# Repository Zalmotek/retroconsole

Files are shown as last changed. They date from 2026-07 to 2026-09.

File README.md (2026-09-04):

# RetroConsole — Arduino UNO Q Retro Game Console

A retro gaming console built on the Arduino UNO Q running Debian Linux, using
RetroArch for emulation with custom Modulino-based controls and an 8″ DSI
touchscreen on the UNO Media Carrier. Boots straight into the game menu —
no keyboard, no desktop.

It optionally also plays the [ARC-AGI-3](#optional-arc-agi-3-puzzle-games)
abstract-reasoning games, on the same gamepad.

Full build write-up: see the project on Arduino Project Hub.

## Architecture

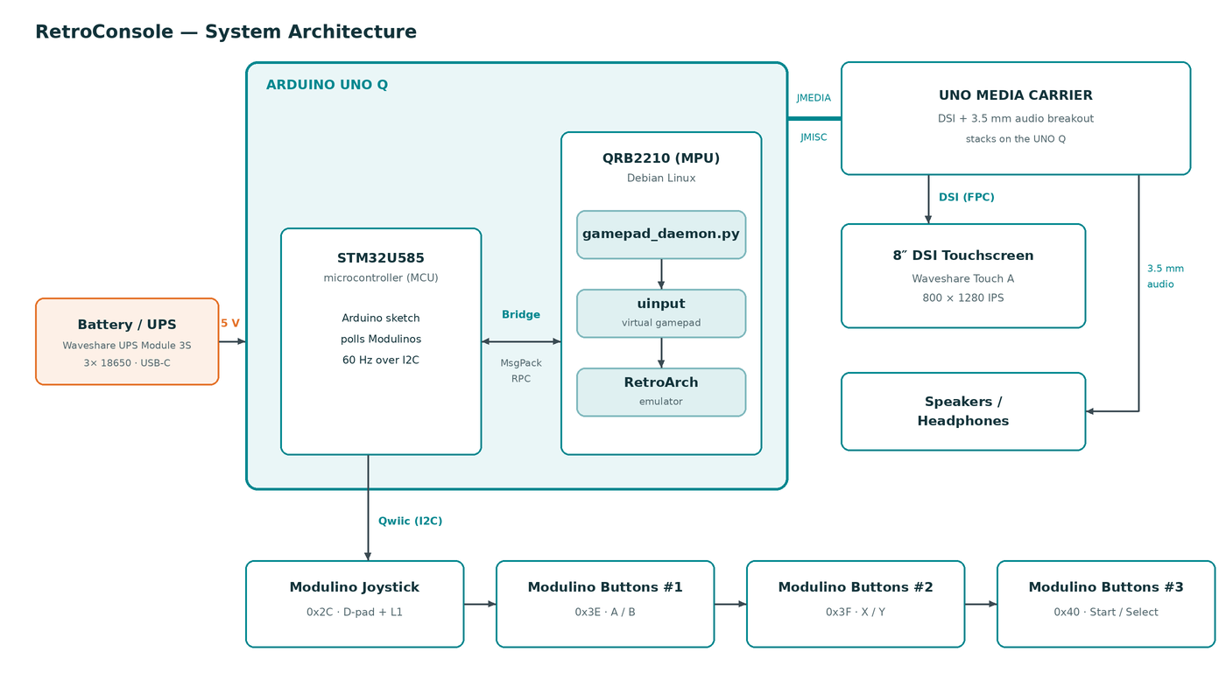
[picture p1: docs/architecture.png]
RetroConsole system architecture


(Diagram source: [`docs/architecture.py`](docs/architecture.py) — edit and re-run to regenerate.)

Each Buttons module contributes only its two **exterior** buttons — the three
buttons sit too close together for the middle one to be usable, so three
modules cover the six actions.

## Hardware

| Component | Purpose | Link |
|---|---|---|
| Arduino Uno Q | Main computing unit (Cortex-A53 + STM32) | [Docs](https://docs.arduino.cc/hardware/uno-q) |
| Uno Media Carrier | DSI display output + 3.5mm audio | [Docs](https://docs.arduino.cc/hardware/uno-media-carrier/) |
| Waveshare 8" DSI touch display (8-DSI-TOUCH-A) | 800x1280 IPS display | [Wiki](https://www.waveshare.com/wiki/8-DSI-TOUCH-A) |
| Waveshare UPS Module 3S + 3x 18650 cells | Battery power / UPS | [Wiki](https://www.waveshare.com/wiki/UPS_Module_3S) |
| Adafruit mono enclosed speaker (3W 4Ω) | Speaker for the enclosed build (earpiece-amp output) | [Adafruit](https://www.adafruit.com/product/4445) |
| USB-C 2-in-1 PD + data adapter | PD power in + USB peripherals on the single USB-C port | [eMAG](https://www.emag.ro/adaptor-usb-c-cu-incarcare-pd-transfer-rapid-12cm-gri-21-typc-2in1/pd/DX295PYBM/) |
| Modulino Buttons x3 | 6 action buttons (A/B/X/Y/Start/Select), exterior pair of each module | [Docs](https://docs.arduino.cc/hardware/modulino-buttons/) |
| Modulino Joystick | Directional control | [Docs](https://docs.arduino.cc/hardware/modulino-joystick/) |

## Wiring

```
[Uno Q] --JMEDIA/JMISC--> [Media Carrier] --15pin FPC--> [Waveshare 8" DSI]
                                |
                                | 3.5mm audio out --> [Speakers/Headphones]

[Uno Q Qwiic] --> [Joystick 0x58] --> [Buttons #1 0x7C] --> [Buttons #2 0x7D] --> [Buttons #3 0x80]
```

## Button Mapping

```
Joystick X/Y   → D-pad (Up/Down/Left/Right)   [both axes inverted in daemon
                                                to match the physical mount]
Joystick Press → L1 (also Hotkey + L1 closes content)
Buttons #1     → A, B          (exterior buttons; middle unused)
Buttons #2     → X, Y          (exterior buttons; middle unused)
Buttons #3     → Start, Select (exterior buttons; middle unused)
```

### Hotkey combos

`Select` is the hotkey modifier. Hold `Select` and press:

| Combo | Action |
|---|---|
| Select + Start | Toggle the in-game menu overlay |
| Select + L1 | Close the running game and return to the (landscape) menu |

Escape is **disabled** as a quit key so a stray USB keypress can't drop the
kiosk to XFCE. To actually quit RetroArch entirely: SSH in and `pkill retroarch`.

## App Lab project bundles

Pre-built zips importable directly into Arduino App Lab live in `dist/`:

- `dist/game-console.zip` — the gameplay sketch + Python skeleton
- `dist/modulino-i2c-changer.zip` — I2C address-change utility (one run per
  extra Buttons module with an explicit target address; see its README)
- `dist/bus-scanner.zip` — Qwiic bus scanner; prints ACKing addresses to the
  App Lab Monitor. Use it to verify the chain and to disarm the changer.
- `dist/recovery-changer.zip` — fixes address collisions (two modules on one
  address) one module at a time.
- `dist/button-checker.zip` — prints every button press/release with its
  gamepad role (A/B/X/Y/Start/Select, D-pad, L1) to the Monitor; standalone
  end-to-end input test before flashing the gameplay sketch.

Re-run `bash dist/build.sh` after editing any source file in `game-console/`
or `modulino-i2c-changer/` to refresh the zips.

## 3D-printed parts

Enclosure files live in [`3d/`](3d/) — STL for printing plus editable source
files.

## Provisioning a Unit

The console is built from three layers, each with its own deployment step. The
order matters — the Linux-side install (Step 4) requires the App Lab project
to have been deployed at least once (Step 3) so the Arduino Router socket and
the `python-apps-base` Docker container exist on the device.

### 1. First boot in App Lab

Install the **latest Arduino App Lab** on your workstation, connect the UNO Q
over USB-C, and complete the first-time setup: set a device name and password,
join Wi-Fi, **enable SSH** in App Lab settings. If App Lab offers an OS
update, take it — the current image ships the Touch A panel drivers and the
`arduino-linux-config` carrier tool, so no manual image flashing is needed.
The steps below assume the device name `retroconsole` — substitute your own.

### 2. Hardware preparation

a. Connect the Uno Q + Media Carrier + Waveshare 8-DSI-TOUCH-A panel +
   speakers. Power via USB-C.
b. **Renumber Buttons #2 and #3** using `dist/modulino-i2c-changer.zip` in
   App Lab (all three Buttons modules ship at the same `0x3E`). Two runs,
   one module attached at a time, editing `NEW_ADDR` between them:
   `0x3F` for #2, `0x40` for #3. Verify each by unplug/replug (blinking
   resumes = persisted), then flash `dist/bus-scanner.zip` to disarm the
   changer and confirm the full chain shows `0x2C, 0x3E, 0x3F, 0x40`.

   Full routine, Monitor/LED codes, and collision recovery:
   [`modulino-i2c-changer/README.md`](modulino-i2c-changer/README.md).
c. Daisy-chain Qwiic in this order:
   `Uno Q → Joystick → Buttons #1 → Buttons #2 → Buttons #3`.

### 3. MCU sketch + first App Lab deploy (workstation, one time)

Install Arduino App Lab on your workstation. Import `dist/game-console.zip`
into App Lab (`File → Import` accepts only zips), then press **Run**. App
Lab will:

- Compile and flash `game-console/sketch/sketch.ino` to the STM32U585 MCU.
  After this step the sketch lives in the MCU's flash and runs on every boot,
  no further App Lab deploys are needed.
- Provision the `python-apps-base` Docker container on the Linux side. We
  don't actually run the App Lab Python app — but the container image needs
  to be on disk so `setup.sh` can copy `arduino.app_utils` out of it.

After this one-time deploy you can disconnect the workstation. The MCU sketch
will run from flash on every boot.

> **Important:** in App Lab's project settings tick **"Run at startup"** on the
> game-console app — otherwise the MCU sketch won't fire on every boot and
> the Linux-side gamepad daemon will see no Bridge traffic.

### 4. Linux-side install (run on the Q)

```bash
ssh arduino@retroconsole.local
git clone https://github.com/Zalmotek/retroconsole.git
cd retroconsole
sudo bash setup.sh
sudo reboot
```

`setup.sh` is idempotent — running it again on a configured unit is harmless.
After the reboot the Q autologs `arduino`, RetroArch starts fullscreen, the
gamepad daemon is already running as a service, and the console is playable.

### 5. DSI panel (enabled automatically by setup.sh)

`setup.sh` enables the Media Carrier + Touch A panel natively via
`arduino-linux-config` (the App Lab carrier tool) — no manual DTB hacking.
It is a no-op when the carrier is already configured, and can be skipped
with `KIOSK_DISPLAY=none sudo bash setup.sh` (HDMI/bench setups). The change
takes effect on the same reboot as the rest of the setup. Manual equivalent:

```bash
sudo arduino-linux-config carrier enable media-carrier display=8-dsi-touch-a
sudo reboot
```

Use `5-dsi-touch-a` / `10-dsi-touch-a` for the other panel sizes
(`arduino-linux-config carrier list` shows the options; `carrier show`
prints the current/next-boot state). On reboot the panel's DRM connector
reports `card0-DSI-1: connected` at its **native `800x1280`** (portrait);
Xorg's rotate-left then presents it as 1280x800 landscape. It's driven by
`panel_jadard_jd9365da_h3` (JD9365, compatible `jadard,jd9365da-h3` /
`waveshare,8.0-dsi-touch-a`), and `arduino-linux-config` composes the
carrier+panel DTB for you. Verify the panel actually came up with:

```bash
sudo arduino-linux-config carrier show   # display -> current: 8-dsi-touch-a
cat /sys/class/drm/card0-DSI-1/status    # connected
cat /sys/class/drm/card0-DSI-1/modes     # 800x1280
```

> Note: enabling the carrier drops the `qrb2210-arduino-imola-video_sound-usbc.dtbo`
> overlay as incompatible — this is expected and is why HDMI-over-USB-C stops
> working (below).

> A fresh image ships with the carrier **disabled** and `display: none`, so
> the panel stays dark until this step runs — RetroArch then starts on a
> 320x200 dummy framebuffer with nothing visible. `carrier show` confirms.

The carrier reroutes the SoC's DSI lanes away from the on-board ANX7625 HDMI
bridge, so **HDMI over USB-C does not work while the carrier is enabled**. To
fall back to HDMI, `arduino-linux-config carrier disable media-carrier` and
physically remove the carrier.

### 6. Add ROMs

```bash
scp "Tobu Tobu Girl.gb" arduino@retroconsole.local:~/roms/gb/
```

Drop ROMs into `~/roms/{gb,gbc,gba,nes,snes,genesis}/` on the Q. RetroArch's
`Load Content` browser starts at `~/roms`. Good open-source homebrew to start
with: [Tobu Tobu Girl](https://tangramgames.dk/tobutobugirl/) (Game Boy) and
[Miniplanets](https://sik.itch.io/miniplanets) (Sega Genesis).

### Verification

If anything misbehaves, on the Q:

```bash
sudo systemctl status modulino-gamepad   # daemon up?
jstest /dev/input/js0                     # raw gamepad — press buttons
evtest /dev/input/event*                  # find 'Modulino Gamepad'
```

## Detailed Setup Guides

1. [OS Setup](setup/01-os-setup.md) — First boot, network, I2C verification
2. [Display Setup](setup/02-display-setup.md) — DSI connection via Media Carrier
3. [Audio Setup](setup/03-audio-setup.md) — Media Carrier line-out
4. [RetroArch Setup](setup/04-retroarch-setup.md) — Installation, config, auto-start

## Supported Systems

| System | Core | Performance |
|---|---|---|
| Game Boy / GBC | gambatte | Full speed |
| Game Boy Advance | mGBA | Full speed |
| NES | Nestopia | Full speed |
| SNES | snes9x | Full speed |
| Sega Genesis | genesis-plus-gx | Full speed |

## Optional: ARC-AGI-3 puzzle games

The console also runs the **ARC-AGI-3** benchmark — the interactive puzzle
games the ARC Prize Foundation uses to measure abstract reasoning. The games
give you no instructions at all: you work out the rules of each world by
acting in it and reading what changes.

```bash
sudo bash install_arc_agi_3_player.sh
```

The installer clones the upstream [Pygame player][arc-upstream], patches it
for a console with no keyboard, downloads the 25 games for offline play, and
adds dock launchers for both apps. It parks the RetroArch autostart, so the
two never fight for the display — you then tap either icon in the dock.

The gamepad drives everything: D-pad moves, A interacts, B undoes, Y resets,
Start opens the menu. The touchscreen covers the grid-click action.

See [arc-agi-3/README.md](arc-agi-3/README.md) for the options, the full
control map and how to restore the RetroArch kiosk.

[arc-upstream]: https://github.com/aashen1/arc-agi-3-local-play

## Project Structure

```
├── setup.sh                            # Idempotent provisioner (re-runnable)
├── game-console/                       # App Lab project — MCU sketch + Python skeleton
├── modulino-i2c-changer/               # App Lab project — 0x3E→0x3F/0x40 renumbering
├── bus-scanner/                        # App Lab project — Qwiic I2C bus scanner
├── recovery-changer/                   # App Lab project — address-collision recovery
├── button-checker/                     # App Lab project — serial button/mapping test
├── dist/                               # Pre-built .zip bundles for App Lab Import
├── modulino-gamepad/
│   ├── gamepad_daemon.py               # Bridge → uinput translator
│   └── modulino-gamepad.service        # systemd unit
├── retroarch/
│   └── modulino-gamepad.cfg            # udev autoconfig (button → RA mapping)
├── kiosk/
│   ├── 10-monitor-dsi-rotate.conf      # Xorg "Rotate left" default
│   ├── 99-touchscreen-rotate-left.rules# libinput touch calibration matrix
│   ├── ra-rotate-watcher.py            # Toggles xrandr on RA game start/exit
│   ├── ra-rotate-watcher.service       # systemd unit for the above
│   ├── retroarch-kiosk.desktop         # Xfce autostart for RetroArch
│   ├── retroarch-overrides.cfg         # RA cfg block appended by setup.sh
│   ├── kiosk-session-watchdog.sh       # Restarts RetroArch if it dies
│   ├── audio-tune.sh                   # Codec tuning re-applied on WirePlumber start
│   ├── usb-host-mode.service           # Forces USB-C to host mode at boot
│   └── 99-kiosk.conf                   # sysctl: disable Magic SysRq
├── 3d/                                 # Enclosure — STL + editable sources
├── setup/                              # Step-by-step guides (hardware focus)
├── install_arc_agi_3_player.sh         # Optional: ARC-AGI-3 puzzle games
└── arc-agi-3/                          # Gamepad bridge, patcher, icon, dock entries
```

## Kiosk Architecture

### Display rotation strategy

The Touch A panel is native portrait 800×1280. The user holds it landscape.
Two facts collide:

1. Xorg's software rotation (`Rotate "left"`) introduces a per-frame
   copy+rotate pass that **races the panel scanout**, producing a fixed-position
   tearline (~70% of the screen width) during horizontal scrolling.
2. RetroArch can rotate its own content inside its swapchain
   (`video_rotation = "1"`), which is tear-free, but only the *game* content
   — the RA menu inherits the screen orientation from the OS.

We get the best of both with a dynamic toggler:

| State | Xorg rotation | RA video_rotation | Result |
|---|---|---|---|
| Menu (no game) | `left` | `1` | Menu reads landscape via X; no scroll → no tear |
| Game running | `normal` | `1` | RA rotates content in swapchain; tear-free |

`kiosk/ra-rotate-watcher.py` polls RetroArch's network command interface
(`GET_STATUS` on UDP 55355) and flips `xrandr --output DSI-1 --rotate` when
content loads / unloads. Installed by `setup.sh` as `ra-rotate-watcher.service`.

### Anti-tearing knobs (`kiosk/retroarch-overrides.cfg`)

- `video_driver = "vulkan"` — Vulkan via Turnip Adreno; presents through
  DRM atomic, tear-free under the msm driver
- `video_vsync = "true"` + `video_hard_sync = "true"` + `video_max_swapchain_images = "3"`
- `video_frame_delay_auto = "true"` — RA times each frame to land just before VBLANK
- xfwm4 compositor disabled (`use_compositing = false`) so RA's vsync isn't
  decoupled by a second compositor

### Audio output modes

`setup.sh` installs `audio-tune.service`, which re-applies codec tuning every
time WirePlumber starts. Two output modes, selected by `/etc/kiosk-audio-output`
(an existing mode file is preserved on re-runs):

- `earpiece` (default) — mono Class-AB earpiece amp driving a bare speaker,
  with a stereo→mono downmix sink (`kiosk/51-earpiece-mono-sink.conf`); for
  the enclosed build
- `headphones` — stereo out on the Media Carrier's MIC-IN/Headphones combo
  jack; for bench builds. Select at provision time:
  `KIOSK_AUDIO_OUTPUT=headphones sudo bash setup.sh`

### USB host mode

`kiosk/usb-host-mode.service` flips the USB-C port from "device" (App Lab
peripheral) to "host" on boot, so external keyboards + USB hubs work. To
re-enable App Lab over USB temporarily, two steps are needed — App Lab talks
ADB, and `adbd` only creates its USB gadget at service start (which happened
while the port was still in host mode), so it must be restarted *after* the
role flip:
```bash
echo device | sudo tee /sys/devices/platform/soc@0/4ef8800.usb/4e00000.usb/usb_role/4e00000.usb-role-switch/role
sudo systemctl restart adbd
```
Verify with `ls /sys/kernel/config/usb_gadget/` — a `g1` entry must exist,
bound to the UDC (`cat /sys/kernel/config/usb_gadget/g1/UDC` → `4e00000.usb`).
If App Lab still shows no device, replug the USB-C cable at the PC end.
Reverts to host mode on the next reboot.

### Touch calibration

The Goodix driver reports `abs_max=4095` but only uses ~0..800 (X) and
~0..1280 (Y) — the panel's pixel coords. `kiosk/99-touchscreen-rotate-left.rules`
applies a scaling matrix (`5.120 0 0 0 3.199 0`) via libinput to map raw
touch onto the X portrait coordinate space; Xorg's RandR rotation handles
the rest when the screen flips.

## Notes

- The Qwiic I2C bus is controlled by the MCU, not Linux. Data flows: Modulinos → MCU (I2C) → Bridge → Linux (Python) → uinput → RetroArch.
- All three Modulino Buttons modules ship at default address `0x3E` (=`0x7C` 8-bit form). Buttons #2 and #3 must be renumbered to `0x3F` and `0x40` using `dist/modulino-i2c-changer.zip` before use — see `modulino-i2c-changer/README.md` for the routine.
- Only the exterior buttons (indices 0 and 2) of each Buttons module are mapped; the middle button is physically too close to its neighbours and is left unused (its LED stays off).
- Carrier presence reroutes the SoC's DSI lanes from the on-board ANX7625 HDMI bridge to the carrier's DSI0 connector — so **HDMI does not work while the carrier is enabled**.
- The MCU sketch must be set to **"Run at startup"** in App Lab; otherwise Bridge stays silent on boot and the gamepad daemon receives no input.
- Bridge.notify() is used for fire-and-forget data transfer (~8ms overhead per call).

## License

MIT — see [LICENSE](LICENSE). Built by [Zalmotek](https://zalmotek.com).

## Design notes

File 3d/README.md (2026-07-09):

# 3D-printed enclosure

- `*.stl` — print-ready meshes
- editable source files (STEP / Fusion 360)

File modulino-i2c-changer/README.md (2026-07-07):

# Modulino I2C Address Changer

Arduino App Lab utility that renumbers a Modulino's I2C address so multiple
modules of the same type can share a Qwiic bus.

The retro-console uses **three Modulino Buttons** (only the exterior pair of
each is mapped — the middle button is too cramped to use). All three ship at
the same factory address, so two of them must be renumbered before the
gamepad sketch can tell them apart:

```
Buttons #1  0x3E  (factory — untouched)
Buttons #2  0x3E → 0x3F
Buttons #3  0x3E → 0x40
```

The changer is **deterministic**: you set the target address explicitly in
the sketch for each run. There is no auto-assignment on purpose — a
half-seated Qwiic connector makes an occupied address look free, which is
how you end up with two modules on one address (see Recovery below).

## From-scratch routine (new unit, 3 fresh Buttons modules)

**Rule 1: exactly one Buttons module on the chain per run.** An I2C write
reaches every device at that address, so two factory modules attached at
once would both be renumbered.
**Rule 2: the changer re-runs on every MCU reset while it's in flash.**
Its guards make that mostly harmless, but always finish with step 5.

The Joystick (0x2C) can stay attached throughout.

1. **Run 1 — make Buttons #2:** attach one Buttons module (alone). Open this
   project in App Lab and press **Run** with the sketch as shipped
   (`NEW_ADDR = 0x3F`). Watch the Monitor: `SUCCESS` + a bus scan. The
   module's three LEDs blink in unison.
2. **Persistence check:** unplug and replug that module. The blinking
   resumes → the address survived the power-cycle. Label the module **#2**
   and detach it.
3. **Run 2 — make Buttons #3:** edit one line in the sketch —
   `NEW_ADDR = 0x40` — attach the second module (alone), press **Run**.
   Same checks. Label it **#3**, detach it.
4. The third module is **Buttons #1**: it stays at the factory `0x3E` —
   no run. Label it anyway.
5. **Disarm:** run the `bus-scanner` app (import `dist/bus-scanner.zip`).
   This removes the changer from MCU flash so later resets can't renumber
   anything, and doubles as the verifier for the next step.
6. **Verify the full chain:** connect
   `Uno Q → Joystick → #1 → #2 → #3` and read the Monitor. It must list
   `0x2C, 0x3E, 0x3F, 0x40`. A missing address = bad connector or cable on
   that segment — reseat until all four show.
7. Flash the gameplay sketch (`game-console`) and test all six buttons.

## Monitor + LED feedback

The Monitor prints the bus before/after and one of:

| Message | Meaning |
|---|---|
| `SUCCESS` | renumbered and verified at the new address |
| `Already at target — nothing to do.` | harmless re-run after a success |
| `REFUSING: target address already in use…` | another module owns NEW_ADDR — detach it first; nothing was changed |
| `FAILED: no module at CURRENT_ADDR…` | nothing answered — almost always a half-seated Qwiic connector |

LEDs on the module: **all three blinking** = success / already done;
**only LED 0** = failed or refused (read the Monitor); **no LEDs** = no
module answered at all.

## Recovery: two (or more) modules on the same address

If addresses ever collide (the classic symptom: a button reads stuck-on,
LEDs won't clear, or the scanner shows fewer Buttons than are attached),
use the `recovery-changer` app (`dist/recovery-changer.zip`): attach **one
module alone**, set its
`NEW_ADDR` to where that module belongs (`0x3E` / `0x40`; the one that
should be #2 needs no run if it's already at `0x3F`), Run, persistence-check,
repeat per module. Finish with the disarm + full-chain verify (steps 5–6).

## Notes

- The address is stored in the module's own flash (non-volatile) — this is
  a once-per-unit operation. Label the modules so units don't get mixed.
- Distance, Thermo, and Movement modules have hardware-fixed addresses and
  cannot be changed.
- If App Lab can't see the board (kiosk image flips USB-C to host mode on
  boot): see "USB host mode" in the main README — role flip to `device`
  **plus** `systemctl restart adbd`.

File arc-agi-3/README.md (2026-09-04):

# ARC-AGI-3 on the Retro Game Console

Turn the console into a machine for the **ARC-AGI-3** benchmark — the
interactive puzzle games the ARC Prize Foundation uses to measure abstract
reasoning. You play them with the Modulino gamepad and the touchscreen.

The games give you no instructions. No tutorial, no goal text, no legend for
the colours. You work out the rules of each world by acting in it and reading
what changes. That is the whole point of the benchmark: it measures how fast a
player builds a theory from nothing. Today humans beat every frontier AI model
on it by a wide margin, and this console lets you feel exactly why.

## What you get

- **25 games**, each with several levels, downloaded once and then played
  fully offline. No account and no API key.
- **Gamepad control.** D-pad moves, A interacts, B undoes, Y resets, Start
  opens the menu. The D-pad auto-repeats when held, for menu scrolling.
- **Touch control** for the grid click action, which some games need, and for
  the menus.
- **Player profiles.** Each player keeps their own progress, level unlocks and
  statistics, so several people can share one console.
- **Replays**, saved in a lightweight JSONL log and in the official ARC-AGI-3
  recording format.
- **RetroArch stays.** Both apps sit in the dock. Tap one to play puzzles,
  tap the other for retro games.

The player is [aashen1/arc-agi-3-local-play][upstream], a Pygame front end for
the official `arc-agi` toolkit. This directory adds what the console needs:
gamepad input, fullscreen, the icon and the dock entries.

## Install

On the console, with a network connection:

```bash
git clone https://github.com/Zalmotek/retroconsole.git ~/retroconsole
cd ~/retroconsole
sudo bash install_arc_agi_3_player.sh
```

It takes about ten minutes, most of it building the Python environment. When
it finishes, tap the **ARC-AGI-3** icon in the dock.

Run `setup.sh` first if the console is new — this script assumes the DSI
panel, the gamepad daemon and the audio are already provisioned.

### Options

| Variable | Effect |
|---|---|
| `ARC_KEEP_KIOSK=1` | Keep RetroArch starting at boot. |
| `ARC_SKIP_DOWNLOAD=1` | Skip the game download, for a console with no network. Press **Sync** in the app later. |
| `ARC_APP_DIR=<path>` | Install somewhere other than `~/arc-play`. |
| `ARC_UPSTREAM_REF=<ref>` | Pin a different upstream commit or tag. |

### What it changes

- Installs the player to `~/arc-play`, in its own Python virtual environment.
  Not pixi: the upstream `pixi.toml` has no `linux-aarch64` platform, and every
  dependency ships an aarch64 wheel, so a plain venv needs no compiler.
- Adds two launchers to the XFCE dock, makes the dock 100 px tall with 80 px
  icons, and turns off autohide. On this 8-inch panel an 80 px icon is about
  10.8 mm, above the 9 mm a fingertip needs.
- Parks the RetroArch autostart as
  `~/.config/autostart/retroarch-kiosk.desktop.disabled`. Both apps want the
  whole display, so only one may start at boot. Restore the old kiosk with:

  ```bash
  mv ~/.config/autostart/retroarch-kiosk.desktop{.disabled,}
  ```

## Controls

| Button | In a menu | In a game |
|---|---|---|
| D-pad | Navigate | Move up, down, left, right |
| A | Confirm | Interact |
| B | Back | Undo |
| X | — | Undo |
| Y | — | Reset the level |
| Start | Confirm | Back to the menu |
| Touch | Tap a button | Tap the grid, for the click action |

On the resume prompt: **A** continues, **X** starts a new game, **Y** opens
level select, **B** goes back.

## Files

| File | Purpose |
|---|---|
| `gamepad.py` | Turns gamepad buttons into key events, per screen. Copied into `human_player/`. |
| `patch-upstream.py` | Adds the gamepad and fullscreen hooks to the upstream checkout. Idempotent, and it stops with a clear message if upstream has moved. |
| `arc-play.sh` | The launcher. Sets an absolute `ENVIRONMENTS_DIR`, forces fullscreen, stops the screen blanking. |
| `panel-launchers/` | The two dock entries. |
| `icons/` | The ARC Prize mark, 16 to 256 px. |

[upstream]: https://github.com/aashen1/arc-agi-3-local-play

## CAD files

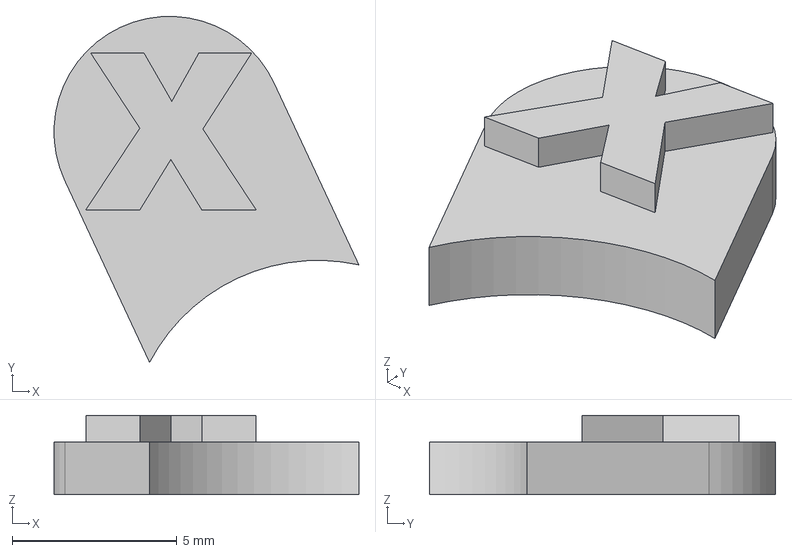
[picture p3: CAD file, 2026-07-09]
3d/x_label.step
9.24 x 10.5 x 2.40 mm

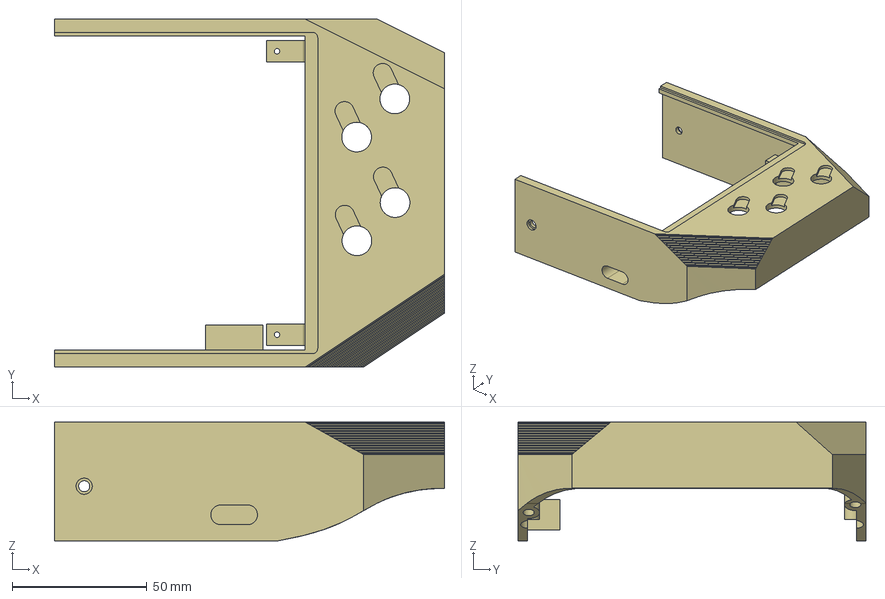
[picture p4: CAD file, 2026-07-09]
3d/console_front_right.step
144.5 x 129.0 x 44.0 mm

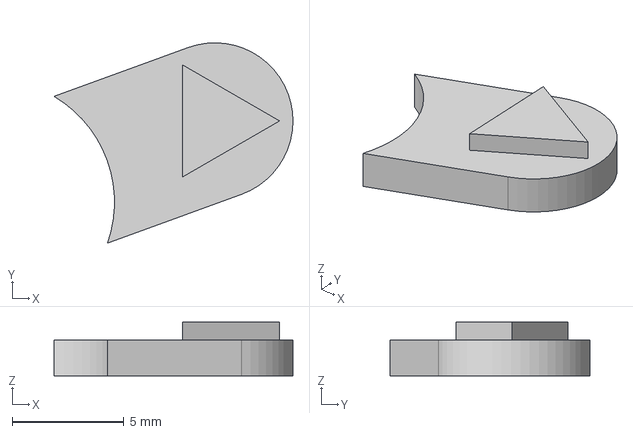
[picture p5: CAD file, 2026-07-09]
3d/menu_label.step
10.7 x 8.98 x 2.40 mm

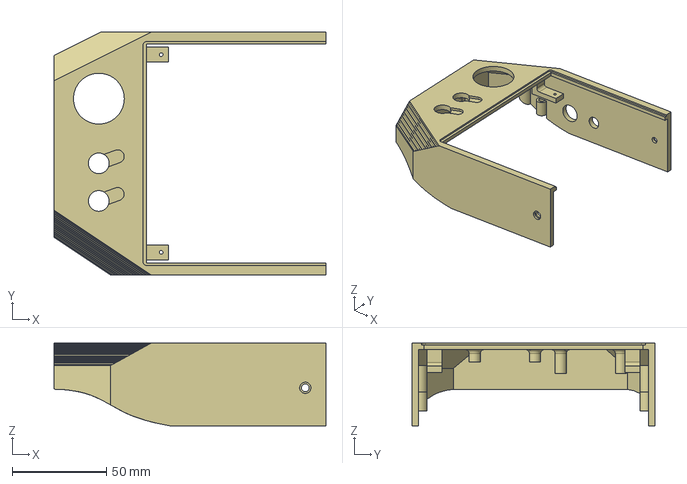
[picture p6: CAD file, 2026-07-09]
3d/console_front_left.step
144.5 x 129.0 x 44.0 mm

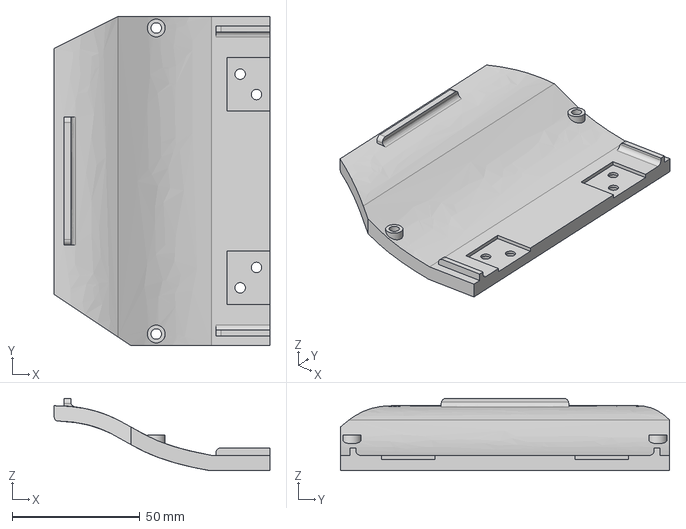
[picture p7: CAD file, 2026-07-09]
3d/console_back_left.step
84.5 x 129.0 x 28.4 mm

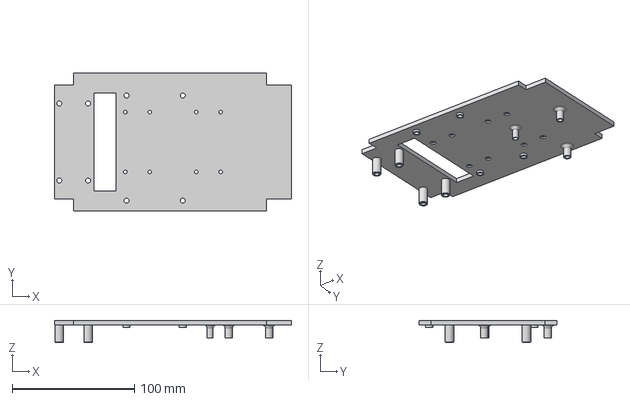
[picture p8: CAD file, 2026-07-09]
3d/modules_mounting_board.step
194.0 x 113.0 x 18.2 mm

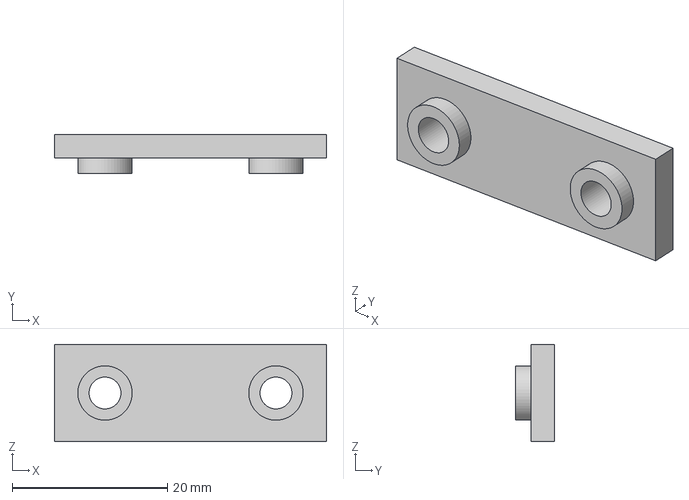
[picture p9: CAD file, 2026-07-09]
3d/fastner.step
35.0 x 5.00 x 12.5 mm

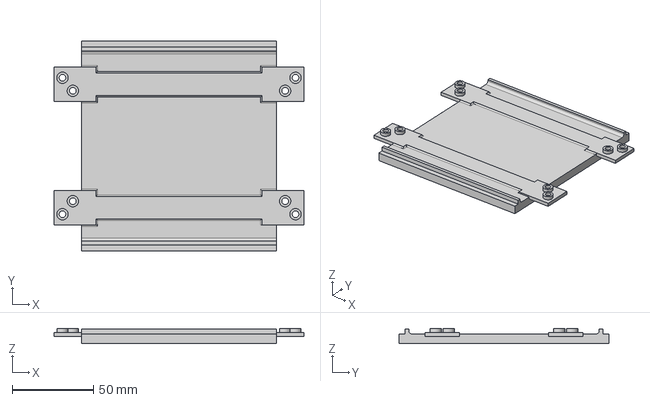
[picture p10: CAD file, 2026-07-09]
3d/console_back_mid.step
153.6 x 129.0 x 9.50 mm

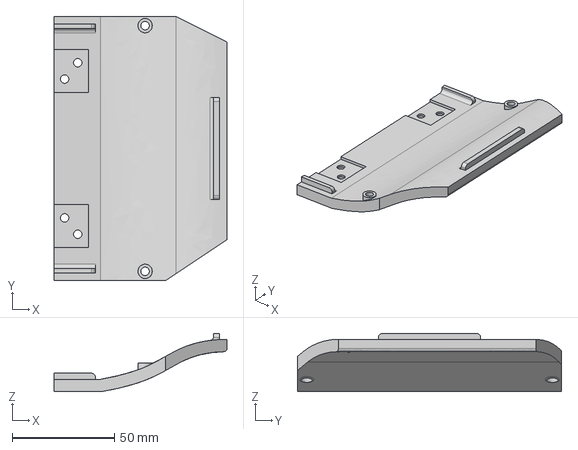
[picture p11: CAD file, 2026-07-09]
3d/console_back_right.step
84.5 x 129.0 x 28.4 mm

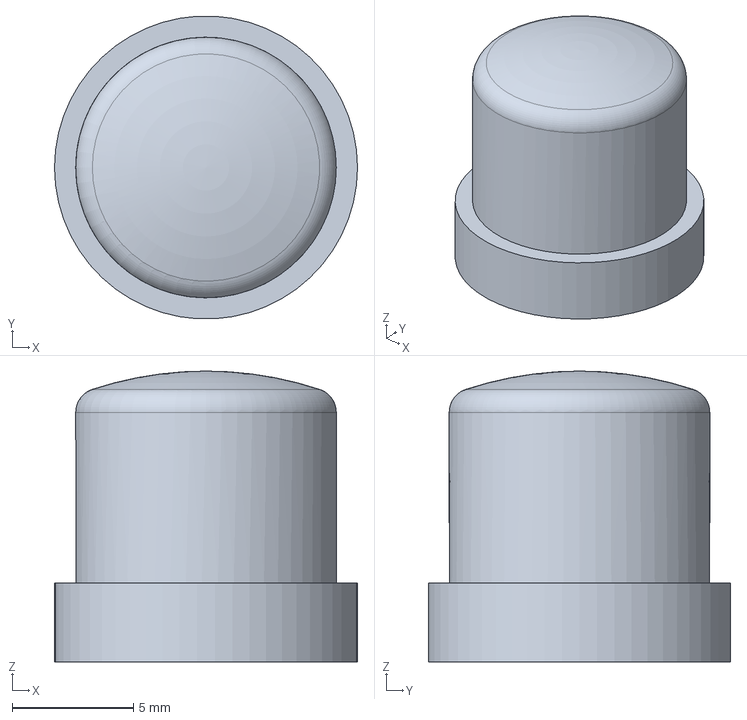
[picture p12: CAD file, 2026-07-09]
3d/button.step
12.5 x 12.5 x 12.0 mm

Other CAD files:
3d/a_label.step
3d/y_label.step
3d/select_label.step
3d/b_label.step
3d/a_label.stl
3d/b_label.stl
3d/button.stl
3d/console_back_left.stl
3d/console_back_mid.stl
3d/console_back_right.stl
3d/console_front_left.stl
3d/console_front_right.stl
3d/fastner.stl
3d/menu_label.stl
3d/modules_mounting_board.stl
3d/x_label.stl
3d/y_label.stl

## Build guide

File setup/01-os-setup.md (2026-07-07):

# OS Setup — Arduino Uno Q

## Prerequisites

- Arduino Uno Q with Debian already flashed
- USB-C cable
- Arduino App Lab on your PC (https://www.arduino.cc/en/software)

## First-Time App Lab Connection

1. Connect the Uno Q to your PC via USB-C
2. Open Arduino App Lab
3. The board will auto-check for firmware/OS updates — install if prompted
4. Set device name, password, and Wi-Fi credentials

## Network Access

After initial setup, you can connect via SSH over Wi-Fi:

```bash
# From your PC
ssh arduino@<device-name>.local
# Default password: set during first-time setup
```

Or connect via USB-C (gadget ethernet):

```bash
ssh arduino@192.168.7.1
```

## Verify I2C (Qwiic bus)

The Qwiic I2C bus is managed by the MCU, not directly accessible from Linux. To verify Modulino devices are connected:

1. Open Arduino App Lab
2. Upload the `File > Examples > Arduino_Modulino > Modulino_Scanner` sketch
3. Check Serial Monitor — it should list detected devices at 0x58, 0x7C, 0x7D

## System Packages

```bash
sudo apt update && sudo apt upgrade -y
sudo apt install -y git python3-pip evtest i2c-tools alsa-utils
```

## Clone This Repo

```bash
git clone <repo-url>
cd retroconsole
```

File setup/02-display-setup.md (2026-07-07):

# Display Setup — Waveshare 8" DSI LCD via Media Carrier

## Enable the panel (native — current method)

The carrier + panel are enabled in software via `arduino-linux-config` (the App
Lab carrier tool) — **no DTB hacking**. A fresh image ships the carrier
**disabled** with `display: none`, so the panel is dark until you run:

```bash
sudo arduino-linux-config carrier enable media-carrier display=8-dsi-touch-a
sudo reboot
```

- `arduino-linux-config carrier list` — show available devices/options
  (`display`: `none, 5-dsi-touch-a, 8-dsi-touch-a, 10-dsi-touch-a`).
- `arduino-linux-config carrier show` — current vs next-boot state.

After reboot the panel is `card0-DSI-1: connected` @ 1280x800, driven by
`panel_jadard_jd9365da_h3` (JD9365). The carrier reroutes the DSI lanes off the
on-board ANX7625, so HDMI-over-USB-C is unavailable while the carrier is enabled
(`carrier disable media-carrier` + remove carrier to use HDMI).

## Hardware Connection

1. Power off the Uno Q
2. Attach the **Uno Media Carrier** via the JMEDIA + JMISC board-to-board connectors
3. Lift the locking tab on the Media Carrier's 22-pin DSI connector
4. Insert the Waveshare display's FPC ribbon cable (contacts facing down)
5. Press the locking tab down to secure

## Boot and Check

Power on. The display may work immediately if the BSP recognizes it.

```bash
# Check DRM/KMS devices
ls /sys/class/drm/

# Look for a connected display
cat /sys/class/drm/card0-DSI-1/status 2>/dev/null

# Check kernel messages for DSI
dmesg | grep -i dsi
dmesg | grep -i panel
```

## If the Display Works

Great — skip to audio setup. RetroArch will use KMS/DRM directly.

Verify with:
```bash
# Should show noise on the display
cat /dev/urandom > /dev/fb0
```

## If the Display Doesn't Work

The Media Carrier officially supports the **Waveshare 8-DSI-TOUCH-A**. The 8" DSI LCD (C) uses the same MIPI-DSI connector but may have a different panel init sequence.

Options:
1. **Check for firmware updates** in Arduino App Lab — newer BSPs may add panel support
2. **Check available DT overlays**: `ls /boot/overlays/ 2>/dev/null || ls /boot/dtbs/`
3. **Use HDMI via USB-C as fallback** — the Uno Q supports DisplayPort Alt-Mode over USB-C, which works with HDMI adapters out of the box

### USB-C HDMI Fallback

If DSI doesn't work, connect a USB-C to HDMI adapter:
```bash
# Display should appear automatically
# Optimal resolution: 1280x720 or 1920x1080
```

## Touch (if DSI works)

The Waveshare capacitive touch controller (Goodix) has a mainline Linux driver:

```bash
# Check if touch device is detected
cat /proc/bus/input/devices | grep -A5 -i touch

# Test
evtest  # select the touch device
```

Touch isn't needed for RetroArch gaming (we use Modulino controls), but it's useful for menu navigation.

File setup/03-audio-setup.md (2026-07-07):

# Audio Setup — Uno Media Carrier

## Hardware

The Uno Media Carrier has a 3.5mm line-out jack. Connect powered speakers or headphones.

## Software Configuration

### Verify Audio Device

```bash
# List audio devices
aplay -l

# You should see an audio device from the Media Carrier
# Look for something like "qrb2210" or "sm8250" audio
```

### Test Audio Output

```bash
# Install audio tools
sudo apt install -y alsa-utils

# Generate and play a test tone
speaker-test -t sine -f 440 -c 2 -l 1

# Or play a WAV file
aplay /usr/share/sounds/alsa/Front_Center.wav
```

### Set Default Output

If multiple audio devices exist, set the Media Carrier as default:

```bash
# Find card number from aplay -l output
# Edit ALSA config
cat > ~/.asoundrc << 'EOF'
defaults.pcm.card 0
defaults.pcm.device 0
defaults.ctl.card 0
EOF
```

### Volume Control

```bash
# Set volume (0-100)
amixer set Master 80%

# Or use interactive mixer
alsamixer
```

## RetroArch Audio Config

RetroArch routes through PipeWire's PulseAudio shim (`pipewire-pulse` is active;
WirePlumber auto-configures the Imola codec headphone path on card 0, so the raw
`amixer` pipeline from the Media Carrier manual is NOT needed). These are applied
by `setup.sh` via `kiosk/retroarch-overrides.cfg`:

```
audio_driver = "pulse"
audio_device = ""
audio_enable = "true"
audio_mute_enable = "false"   # default profile ships this as "true" → silent games
audio_sync = "true"
audio_latency = "64"
```

## Codec tuning (headphone amp quality)

The Imola codec headphone amp comes up in a low-power, distorting default. Tuned
values (chosen by listening test) are applied by `audio-tune.service`, a user
service bound to `wireplumber.service` (so it re-runs whenever WirePlumber
restarts and resets the codec):

```
amixer -c0 sset 'RX_HPH PWR Mode' ULP      # best with the current amp board
amixer -c0 sset 'RX_HPH HD2 Mode' on       # 2nd-harmonic distortion correction
wpctl set-volume @DEFAULT_AUDIO_SINK@ 0.90 # source level; final loudness on amp
# balance: WirePlumber drives only RX_RX1 (right) from the sink slider, so mirror
# left = right AFTER setting the sink, or the channels are uneven:
RIGHT=$(amixer -c0 cget iface=MIXER,name='RX_RX1 Digital Volume' | grep -oE 'values=[0-9]+' | tail -1 | cut -d= -f2)
amixer -c0 cset iface=MIXER,name='RX_RX0 Digital Volume' "$RIGHT"
```

> **Channel balance gotcha:** `RX_RX1 Digital Volume` (right) *is* the sink
> volume — WirePlumber maps the slider onto it and leaves `RX_RX0` (left)
> alone, so the two channels drift apart. There's no independent "set codec to
> N and sink to M"; the right codec value is whatever the slider dictates. The
> only fix is to mirror left = right after the sink is set (audio-tune.sh does
> this automatically each boot).

- `RX_HPH PWR Mode`: the best mode is **amp-dependent**. `LOHIFI` won on the
  first amp; `ULP` won on the current amp board. Re-run the listening test
  (A: LOHIFI+HD2on, B: LOHIFI+HD2off, C: ULP+HD2on, D: ULP+HD2off) if the amp changes.
- `RX_HPH HD2 Mode`: `on` consistently helped; `off` was audibly worse.
- **Do NOT touch `RX INT0/1 DEM MUX`** — switching Class-H (`CLSH_DSM_OUT`) to
  `NORMAL_DSM_OUT` silences the headphone output entirely, and toggling it live
  wedges the codec until `systemctl --user restart wireplumber`.
- The `HPHL`/`HPHR` analog gain spans only ~1.4 dB — useless as a volume control.
- For an external amp: keep the digital sink moderate (~50%) and set final
  loudness on the amp; the dedicated **Line Out (`hw:0,1`) is mono/differential**,
  not a stereo line out.

## Troubleshooting

- **No sound in games but system beep works**: RetroArch is muted —
  `audio_mute_enable = "true"`. Set it to `"false"` (setup.sh pins this), or
  live-toggle on the running kiosk: `echo -n MUTE | nc -u -w1 127.0.0.1 55355`.
- **No sound**: Check `amixer` isn't muted, verify correct card in `aplay -l`,
  and that the default sink is at volume: `wpctl get-volume @DEFAULT_AUDIO_SINK@`
- **Crackling**: Increase `audio_latency` in RetroArch (try 128)
- **No audio device**: Media Carrier may need kernel module; check `dmesg | grep audio`

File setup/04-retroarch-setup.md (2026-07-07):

# RetroArch Setup

## Installation

```bash
# Install RetroArch and common cores
sudo apt install -y retroarch \
  libretro-gambatte \
  libretro-snes9x \
  libretro-mgba \
  libretro-genesis-plus-gx \
  libretro-nestopia

# If packages aren't available, build from source:
# sudo apt install -y build-essential git libdrm-dev libasound2-dev
# git clone https://github.com/libretro/RetroArch.git
# cd RetroArch
# ./configure --disable-x11 --enable-kms --enable-alsa
# make -j4
# sudo make install
```

## Gamepad Configuration

Install the Modulino Gamepad autoconfig:

```bash
mkdir -p ~/.config/retroarch/autoconfig/udev/
cp ~/retroconsole/retroarch/modulino-gamepad.cfg \
   ~/.config/retroarch/autoconfig/udev/
```

## Display Configuration

Edit `~/.config/retroarch/retroarch.cfg`:

```
video_driver = "kms"
video_fullscreen = "true"
video_windowed_fullscreen = "false"
video_monitor_index = "0"
```

## Audio Configuration

```
audio_driver = "alsa"
audio_enable = "true"
audio_sync = "true"
audio_latency = "64"
```

## Auto-Start RetroArch on Boot

Create a systemd service:

```bash
sudo tee /etc/systemd/system/retroarch.service << 'EOF'
[Unit]
Description=RetroArch Emulator
After=modulino-gamepad.service
Wants=modulino-gamepad.service

[Service]
Type=simple
User=arduino
Environment=XDG_RUNTIME_DIR=/run/user/1000
ExecStart=/usr/bin/retroarch --config ~/.config/retroarch/retroarch.cfg
Restart=on-failure
RestartSec=5

[Install]
WantedBy=graphical.target
EOF

sudo systemctl daemon-reload
sudo systemctl enable retroarch
```

## Adding ROMs

Place ROM files in the RetroArch content directory:

```bash
mkdir -p ~/roms/{gb,gbc,gba,snes,nes,genesis}
# Copy your legally obtained ROMs into the appropriate folders
```

## Testing

```bash
# Start the gamepad daemon first
sudo systemctl start modulino-gamepad

# Launch RetroArch manually for testing
retroarch

# Navigate menus with the joystick, load a ROM, verify controls
```

## Performance Tips

- The A53 @ 2GHz handles GB, GBC, GBA, NES, SNES, and Genesis well
- For SNES, use snes9x (lighter than bsnes)
- Avoid N64/PS1 cores — they'll likely be too slow
- If frames drop, try: Settings → Video → Threaded Video = ON

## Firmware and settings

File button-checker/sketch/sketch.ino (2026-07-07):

/*
 * Button checker — prints every press/release to the App Lab Monitor with
 * the gamepad role each button is mapped to in the game-console sketch.
 * Standalone (no Bridge / Linux daemon needed). LEDs mirror presses, same
 * as the gameplay sketch (middle LEDs stay off — middle buttons are unused).
 *
 * Expected chain: Joystick 0x2C, Buttons #1 0x3E, #2 0x3F, #3 0x40.
 * Modules that don't answer at startup are reported and skipped.
 *
 * D-pad directions follow the daemon's convention (axes inverted to match
 * the physical mount): push left on the mounted console → "D-pad LEFT".
 */

#include <Wire.h>
#include <Modulino.h>

constexpr int DEAD_ZONE = 25;  // same as gamepad_daemon.py

struct Pad {
  uint8_t     addr;
  const char *name;
  const char *role[3];
};

Pad pads[3] = {
  { 0x3E, "Buttons #1", { "A",     "(middle, unused)", "B"      } },
  { 0x3F, "Buttons #2", { "X",     "(middle, unused)", "Y"      } },
  { 0x40, "Buttons #3", { "Start", "(middle, unused)", "Select" } },
};

ModulinoButtons  b1(0x3E), b2(0x3F), b3(0x40);
ModulinoButtons *mod[3] = { &b1, &b2, &b3 };
ModulinoJoystick joystick;

bool padAlive[3], joyAlive;
bool lastBtn[3][3];
bool lastJoyBtn = false;
int  lastDirX = 0, lastDirY = 0;

bool present(uint8_t addr) {
  Wire1.requestFrom(addr, (uint8_t)1);
  bool found = Wire1.available() > 0;
  while (Wire1.available()) Wire1.read();
  return found;
}

void setup() {
  Serial.begin(115200);
  while (!Serial && millis() < 5000) {}
  Wire1.begin();
  delay(600);
  Modulino.begin();

  Serial.println("=== Modulino Gamepad button checker ===");
  Serial.println("Mapping: #1 ext = A/B | #2 ext = X/Y | #3 ext = Start/Select");
  Serial.println("Joystick: D-pad; press = L1");
  Serial.println("Hotkeys:  Select+Start = RA menu | Select+L1 = quit game");
  Serial.println();

  joyAlive = present(0x2C);
  Serial.print("Joystick 0x2C: ");
  Serial.println(joyAlive ? "OK" : "MISSING");
  if (joyAlive) joystick.begin();

  for (int p = 0; p < 3; p++) {
    padAlive[p] = present(pads[p].addr);
    Serial.print(pads[p].name);
    Serial.print(" 0x");
    Serial.print(pads[p].addr, HEX);
    Serial.print(": ");
    Serial.println(padAlive[p] ? "OK" : "MISSING");
    if (padAlive[p]) mod[p]->begin();
  }
  Serial.println("\nPress buttons / move the joystick...\n");
}

void loop() {
  for (int p = 0; p < 3; p++) {
    if (!padAlive[p]) continue;
    mod[p]->update();
    for (int i = 0; i < 3; i++) {
      bool cur = mod[p]->isPressed(i);
      if (cur != lastBtn[p][i]) {
        lastBtn[p][i] = cur;
        Serial.print(cur ? "PRESSED  " : "released ");
        Serial.print(pads[p].name);
        Serial.print(" btn ");
        Serial.print(i);
        Serial.print("  ->  ");
        Serial.println(pads[p].role[i]);
      }
    }
    // LED feedback like the gameplay sketch: exterior LEDs follow presses.
    mod[p]->setLeds(lastBtn[p][0], false, lastBtn[p][2]);
  }

  if (joyAlive) {
    joystick.update();
    int  x   = joystick.getX();
    int  y   = joystick.getY();
    bool jb  = joystick.isPressed();
    int  dx  = (x > DEAD_ZONE) ? -1 : (x < -DEAD_ZONE) ? 1 : 0;  // daemon-inverted
    int  dy  = (y > DEAD_ZONE) ? 1 : (y < -DEAD_ZONE) ? -1 : 0;

    if (jb != lastJoyBtn) {
      lastJoyBtn = jb;
      Serial.print(jb ? "PRESSED  " : "released ");
      Serial.println("Joystick button  ->  L1");
    }
    if (dx != lastDirX) {
      lastDirX = dx;
      if (dx) Serial.println(dx < 0 ? "D-pad LEFT" : "D-pad RIGHT");
      else    Serial.println("D-pad X centered");
    }
    if (dy != lastDirY) {
      lastDirY = dy;
      if (dy) Serial.println(dy > 0 ? "D-pad DOWN" : "D-pad UP");
      else    Serial.println("D-pad Y centered");
    }
  }

  delay(16);
}

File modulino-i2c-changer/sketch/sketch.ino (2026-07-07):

/*
 * Modulino I2C Address Changer — deterministic, one module per run.
 *
 * Renumbers ONE Modulino Buttons module from CURRENT_ADDR to NEW_ADDR.
 * No auto-assignment: a flaky Qwiic connector makes an occupied address
 * look free, so the target is always set explicitly below.
 *
 * FROM-SCRATCH ROUTINE for the 3-module retro-console (full steps in
 * README.md). One Buttons module attached at a time, joystick may stay:
 *
 *   Run 1:  NEW_ADDR = 0x3F   → that module becomes Buttons #2
 *   Run 2:  NEW_ADDR = 0x40   → that module becomes Buttons #3
 *   The untouched third module stays 0x3E and is Buttons #1.
 *
 * Then FLASH SOMETHING ELSE (the bus-scanner app or game-console) before
 * rebuilding the full chain: this sketch re-runs on every MCU reset for as
 * long as it sits in flash.
 *
 * Monitor output shows the bus before/after and the verdict. LED feedback
 * on the module:
 *   all three blinking  → success (or already at target)
 *   only LED 0 blinking → failed / refused — read the Monitor
 *   no LEDs at all      → no module answered — check the connectors
 *
 * After a success, unplug/replug the module: if the blinking RESUMES, the
 * new address persisted across the power-cycle.
 *
 * Safety guards (what makes re-runs and stray resets harmless):
 *   - target already occupied AND source present  → refuses, changes nothing
 *   - module already at target, none at source    → reports done, no write
 *   - nothing at source                           → reports failure, no write
 *
 * Works for other module types too — set CURRENT_ADDR / NEW_ADDR. Defaults
 * (7-bit, pinstrap = value × 2): Buttons 0x3E, Joystick 0x2C, Buzzer 0x1E,
 * Smartleds 0x36, Vibro 0x38, Opto Relay 0x14, Encoder 0x3B/0x3A.
 * Distance / Thermo / Movement are hardware-fixed and cannot be changed.
 */

#include <Wire.h>
#include <Modulino.h>

// ---- Edit per run -----------------------------------------------------------
constexpr uint8_t CURRENT_ADDR = 0x3E;  // factory default (Buttons)
constexpr uint8_t NEW_ADDR     = 0x3F;  // run 1 (#2): 0x3F  |  run 2 (#3): 0x40
// ------------------------------------------------------------------------------

void scanBus() {
  int found = 0;
  for (uint8_t a = 0x08; a <= 0x77; a++) {
    Wire1.beginTransmission(a);
    if (Wire1.endTransmission() == 0) {
      Serial.print("  ACK at 0x");
      Serial.println(a, HEX);
      found++;
    }
  }
  if (!found) Serial.println("  nothing found");
}

bool present(uint8_t addr) {
  Wire1.requestFrom(addr, (uint8_t)1);
  bool found = Wire1.available() > 0;
  while (Wire1.available()) Wire1.read();
  return found;
}

void blinkForever(uint8_t addr, bool ok) {
  ModulinoButtons buttons(addr);
  buttons.begin();
  while (true) {
    buttons.setLeds(ok, ok, ok);
    delay(250);
    buttons.setLeds(!ok, false, false);
    delay(250);
  }
}

void setup() {
  Serial.begin(115200);
  while (!Serial && millis() < 5000) {}
  Wire1.begin();
  delay(600);
  Modulino.begin();

  Serial.println("Bus before:");
  scanBus();

  bool srcHere = present(CURRENT_ADDR);
  bool dstHere = present(NEW_ADDR);

  if (dstHere && !srcHere) {
    Serial.println("Already at target — nothing to do.");
    blinkForever(NEW_ADDR, true);
  }
  if (dstHere && srcHere) {
    Serial.println("REFUSING: target address already in use by another module.");
    Serial.println("Detach the module that owns it (or pick another NEW_ADDR).");
    blinkForever(CURRENT_ADDR, false);
  }
  if (!srcHere) {
    Serial.println("FAILED: no module at CURRENT_ADDR. Check the Qwiic");
    Serial.println("connectors — they need a firm click on both ends.");
    blinkForever(CURRENT_ADDR, false);
  }

  // Modulino address-change frame: 'C' 'F' <newAddr*2>, padded to 40 bytes.
  uint8_t data[40] = { 'C', 'F', static_cast<uint8_t>(NEW_ADDR * 2) };
  Wire1.beginTransmission(CURRENT_ADDR);
  Wire1.write(data, 40);
  Wire1.endTransmission();
  delay(500);

  bool ok = present(NEW_ADDR);
  Serial.println(ok ? "SUCCESS — unplug/replug the module; if the blinking"
                      "\nresumes, the new address persisted."
                    : "FAILED: no response at the new address.");
  Serial.println("Bus after:");
  scanBus();

  blinkForever(ok ? NEW_ADDR : CURRENT_ADDR, ok);
}

void loop() {}

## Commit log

2026-07-07 RetroConsole — Arduino UNO Q retro game console (public release)
    [modulino-gamepad.cfg, retroarch-overrides.cfg]
2026-07-09 3d: add printable enclosure — STL meshes + STEP sources
    [a_label.step, a_label.stl, b_label.step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]
